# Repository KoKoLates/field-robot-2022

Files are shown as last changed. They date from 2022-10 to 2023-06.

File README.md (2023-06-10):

# Field Robot 2022
###### tags: `ntu bme` 、 `field robot`

The hardware and source codes using for field robot competition 2022.

## Features
* System consists of nvidia jetson nano and Arduino mega 2560, with transmission via serial.
* Design the robotic arm and apply the inverse kinematic to control by giving the target position.
* Implements a lane tracking algorithm for synthetic grass paths using opencv image processing, allowing robot to follow along the appropriate path.

## Overview
[**circuit**](./circuit/) | [**robotic cart**](./robotic_cart/) | [**robotic arm**](./robotic_arm/) 
| [**resources**](./assets/resources/) | [**images**](./assets/images/)

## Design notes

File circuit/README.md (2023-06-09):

# Circuit Designs
`Electric components` 、 `circuit designs` <br>

__1. Computational Unit__ <br>

* arduino mega -> `dc motor control` / arduino nano -> `servo motor`
* raspberry pi 4 (`wip`/`template`)
* nvidia jetson nano

__2.Electrical Unit__ <br>

* IBT2 -> `H-Bridge`
* voltage converter `HW319-V6.0` / voltage indicator
* battery (`12v`) / battery pack (`5v/2a`) for computation unit
* emergency button `LA38`

__3.Sensors and Acuator__ <br>

* step motor and servo motor
* relay `SRD-05VDC-SL-C` -> water pump

## Implements
###### tags:  `controller`、 `h-bridge`、 `regulator`、 `dc motor`

* Testing the driven part that connect the dc motor with h-bridge (`L298n`) and `12v` dc battery (here we test on power supplier first).
* Using the arduino mega as the controller for `PWN` signal output.
* check the general switch and emergency button work properly.

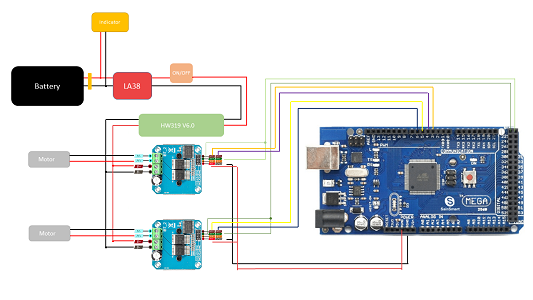
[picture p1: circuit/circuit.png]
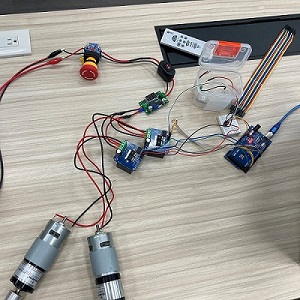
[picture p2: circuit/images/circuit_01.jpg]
 

###### tags: `eletric boxes` 、 `water-proof`
* The voltage for each components are indicating strictly.
* The all important unit for controll and operation are places inside the water-proof container both for robotic cart and for the dummy arm.
* There are maly three type of voltage being managed. `12v` for DC motor driven; two `5v` one is for the main controller and other sensors, the other is for the servo motor on the robotic arm which is driven by the servo driver (`PCA9685`).

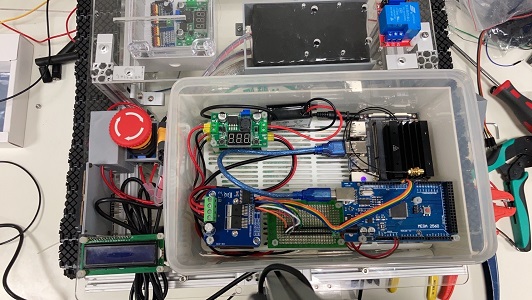
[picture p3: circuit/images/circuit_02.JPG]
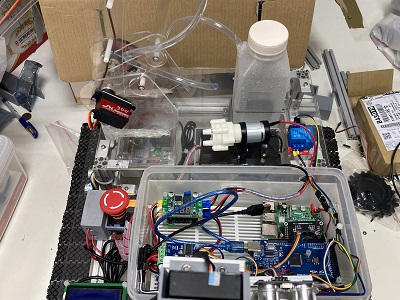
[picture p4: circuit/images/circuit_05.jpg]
 

---
[`Components Lists`](./components_list.pdf)

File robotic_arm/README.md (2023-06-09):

# Robotic Arm
`robotic arm` 、 `servo motor` 、 `gripper`

## Servo Motor
* `MG996R` for arm machenism / `SG90` for gripper.
* `PCA9685` servo driver for multi-servo PWM manager, control and driving.
* The import unit are stored inside the water-proof container.
*  [`motor driver | adafruit_PCA9685 pwm library`](http://adafruit.github.io/Adafruit-PWM-Servo-Driver-Library/html/class_adafruit___p_w_m_servo_driver.html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)

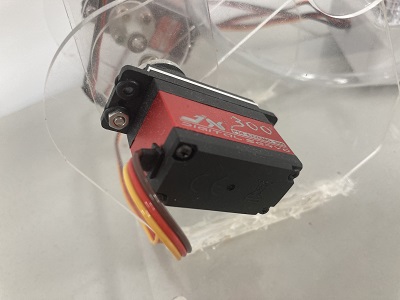
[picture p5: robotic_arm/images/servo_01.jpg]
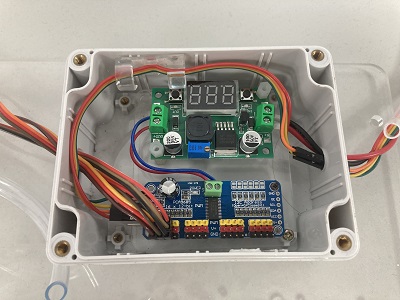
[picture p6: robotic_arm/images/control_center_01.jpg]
 

**Implements**

The are two type of design we use in the first
* Using another controller (`Aduino Nano`) for edge controll and communicate with main controller in `I2C` protocal
* Using the main controller in the center direcly.

## Robotic Arm
`robotic arm design` 、 `inverse kinematic`

__Designs in CAD__

The prototype of dummy robotic arm.


__Outcomes__

* The arm is manufactor in `acrylic` material.
* Using the `483` bearing for connect each components with free degree ratation.
* The Spacer could also help fix the wire and water pip.

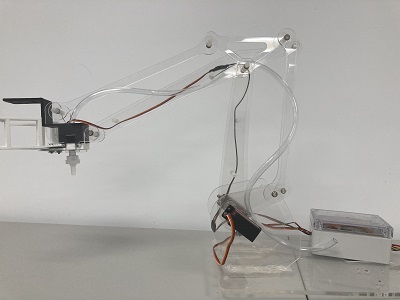
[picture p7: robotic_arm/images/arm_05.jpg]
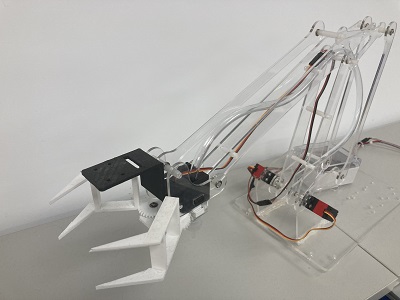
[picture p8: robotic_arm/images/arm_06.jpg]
 

__Inverse Kinematic__

For more convinent to controll the robot arm to grip the specific object. We use the inverse kinematic to calculate that by giving the object position, and the cooresponding servo angle would be. Thus, we could using some object detection algorithms to get the coordinate of object, then using the `API` we build to controll the arm properly.

* `resetInit()` reset the robotic arm to the initialize status.
* `moveTo(int x, int y)` set the end side (griper side) to the cooresponding position coordinate in the space.

## Gripper
We design a simple gripper for the object gripping.

* `SG90` servo motor.
* Small camera for `depth` information update.
* check valve and pip for watering task.

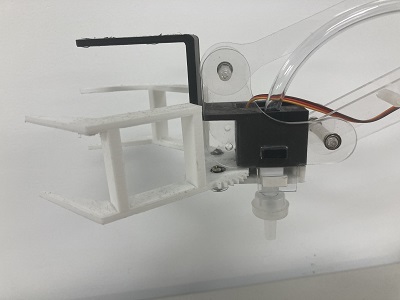
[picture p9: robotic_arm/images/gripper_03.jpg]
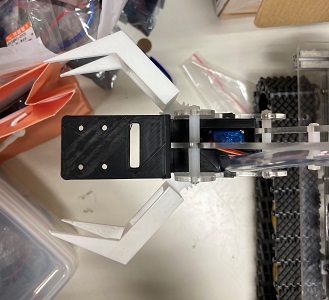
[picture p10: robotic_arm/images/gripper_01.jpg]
 

**API**
* `grab()` set the gripper close to gripping the object.
* `ungrab()` release the gripper.

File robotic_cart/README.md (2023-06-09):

# Robotic Cart
`robotic cart` 、 `side panel` 

## Scroll wheel and Support Structures
Due to the robot is go through in the outdoor field environments, we hope to design `shock absorber` 、 `continuous track` scroll wheel.

__1. Designs in CAD__

* crank rocker mechanism.
* springs and bearings.

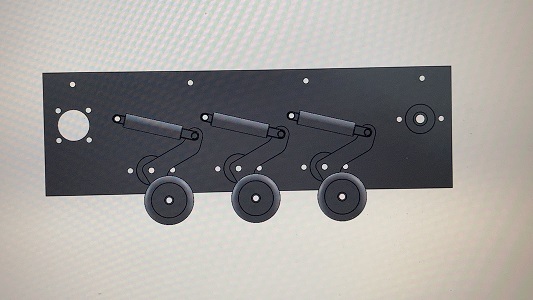
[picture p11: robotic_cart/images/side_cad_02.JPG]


__2. Wheel Axles__

* lathing two axles for the back wheel.

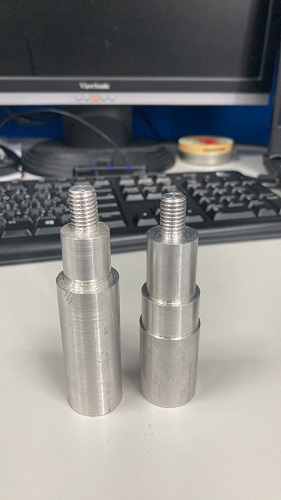
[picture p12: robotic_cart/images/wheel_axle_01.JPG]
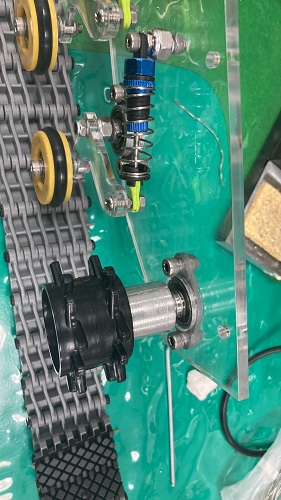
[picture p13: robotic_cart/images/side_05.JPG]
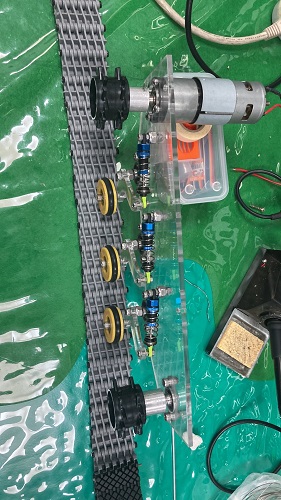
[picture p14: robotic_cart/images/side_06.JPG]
  

__3. Outcomes__

* The track is driven by the `DC motor` in the front.
* Once encounter any strike, the spring and machanism would absorb the shock.

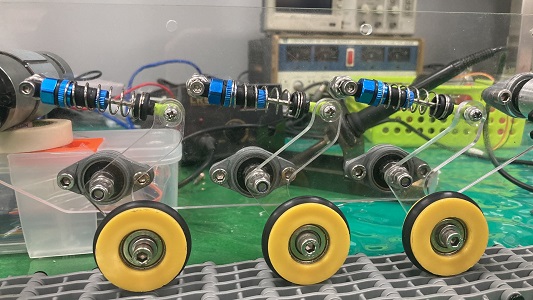
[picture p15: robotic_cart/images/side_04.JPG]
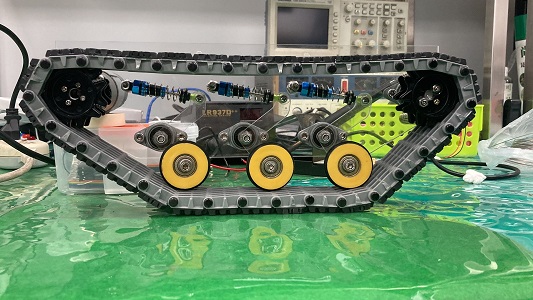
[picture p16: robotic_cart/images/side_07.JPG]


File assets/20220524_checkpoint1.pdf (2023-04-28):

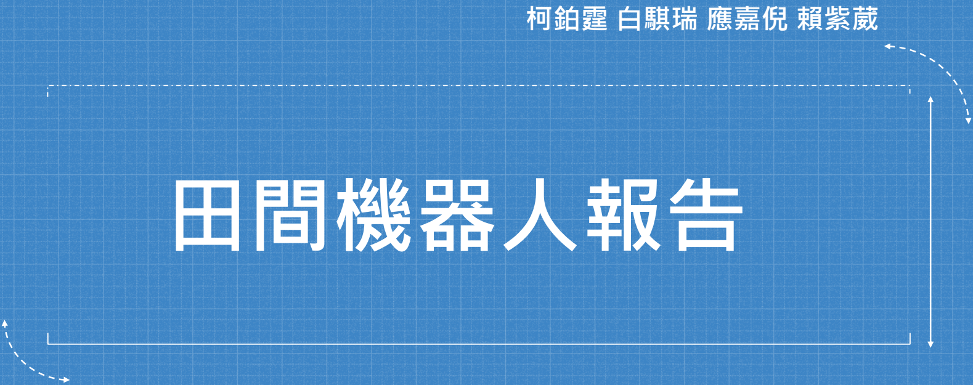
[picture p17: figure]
田間機器人報告; 柯鉑霆 白騏瑞 應嘉倪 賴紫葳

目錄

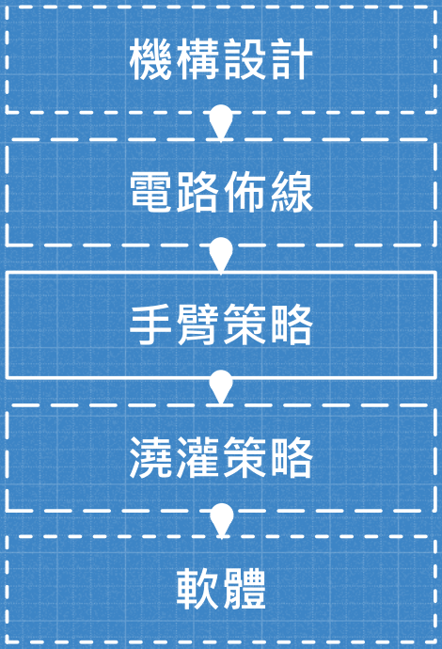
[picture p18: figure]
電路佈線; 手臂策略; 機構設計; 澆灌策略

# 機構設計

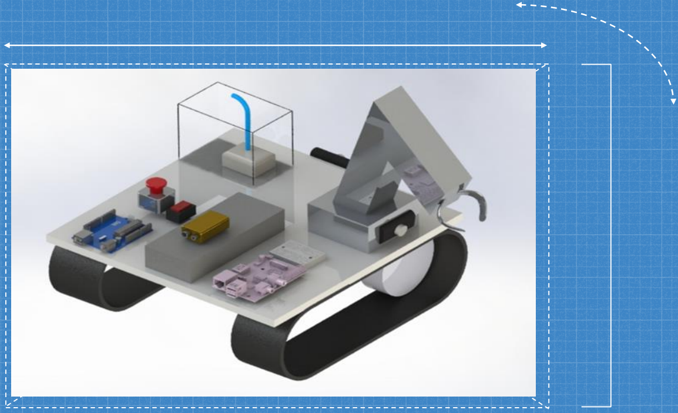
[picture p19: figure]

### - 正方形車底板

### - 一層設計

### - 鋁擠、壓克力板

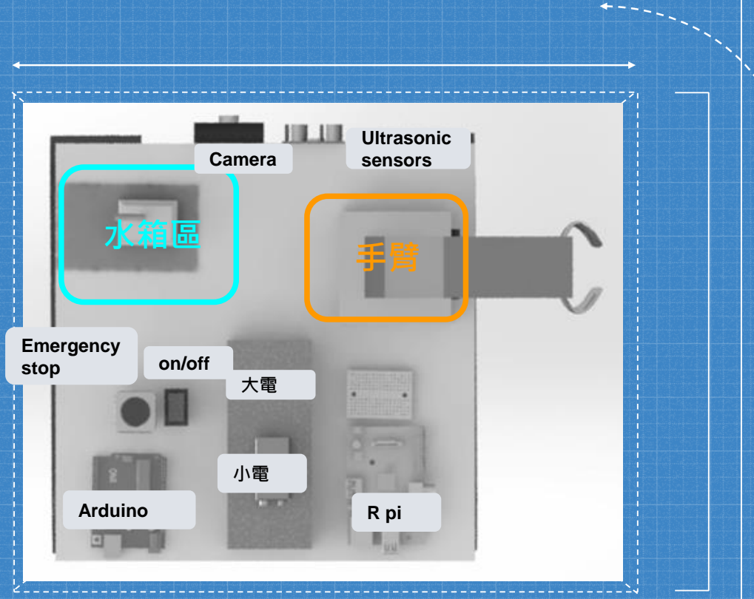
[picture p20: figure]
水箱區; Arduino; Emergency stop; on/off; Camera; Ultrasonic sensors

# 機構設計

### - 擺放位置安排

車體最前端— 視野清晰
前半部分— 重心位置
後半部分—方便接線&調整

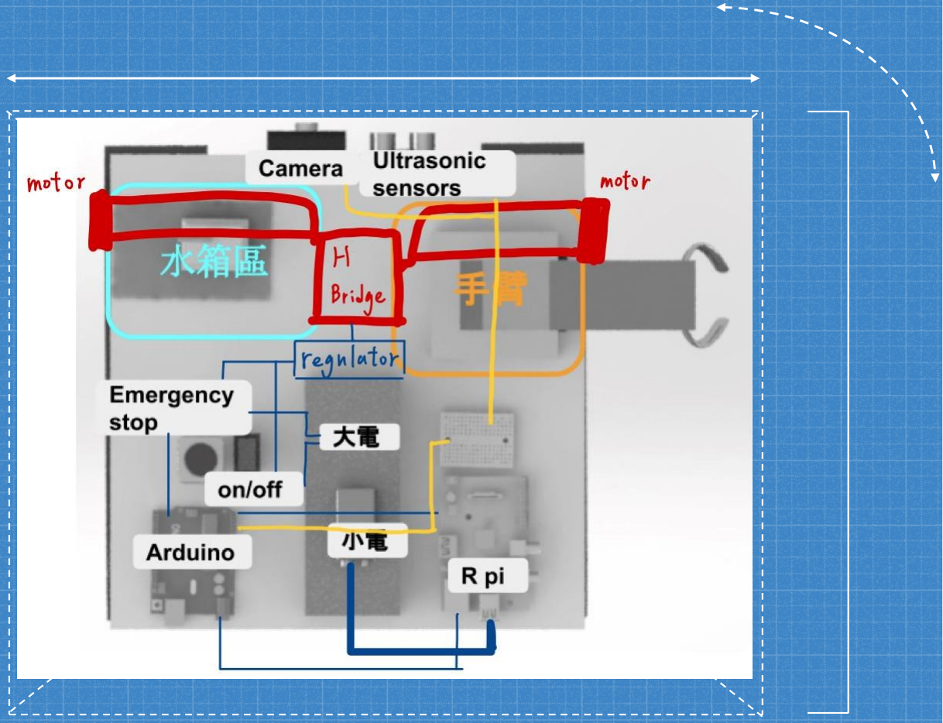
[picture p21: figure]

# 電路佈線

# 手臂策略

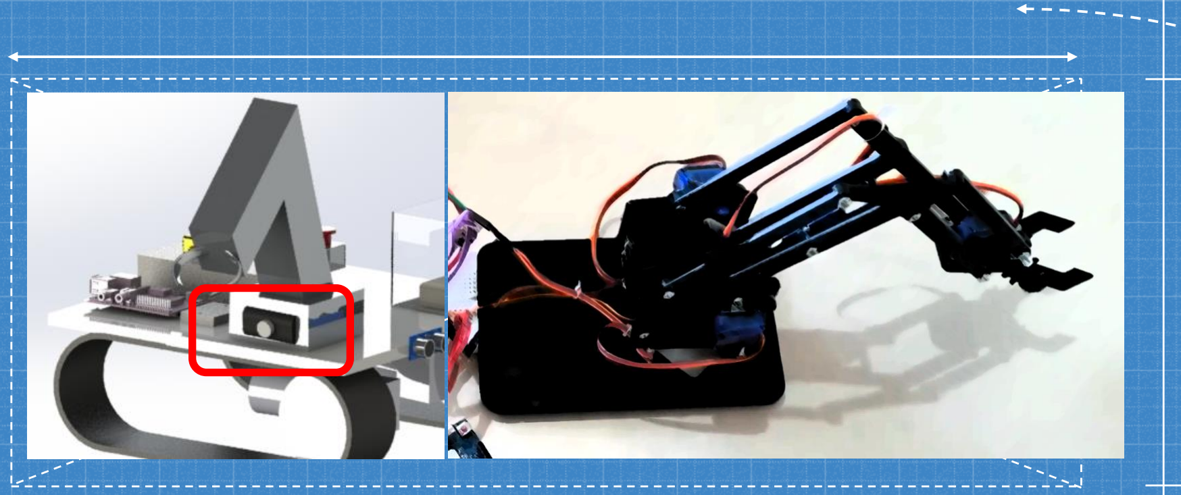
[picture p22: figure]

- 二軸

### - 三個步進馬達

### - 相機位置固定

# 澆灌策略

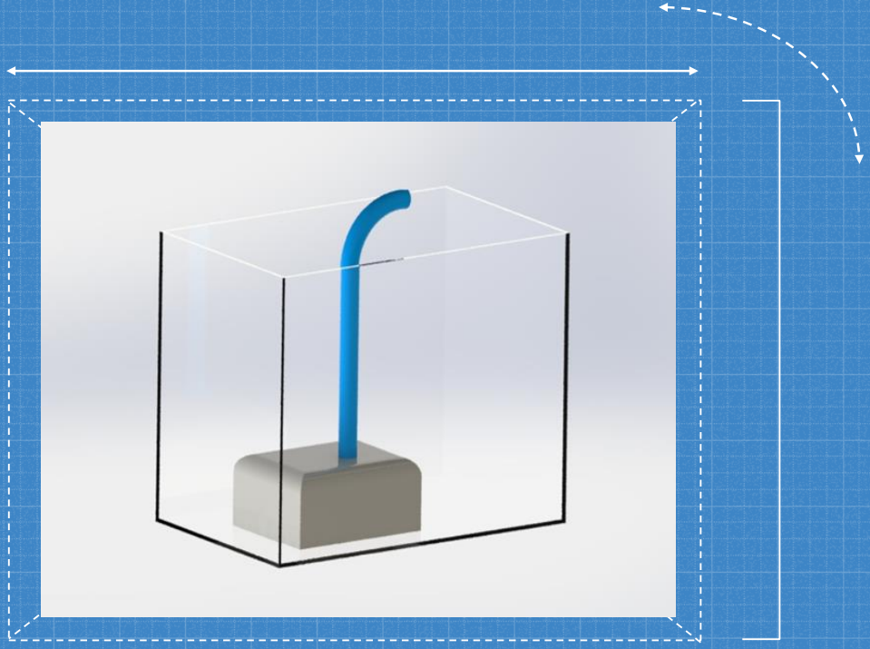
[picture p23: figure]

### - 抽水方式 小型沉水式馬達

### - 水管連接夾爪

### - 定位方式同手臂策略

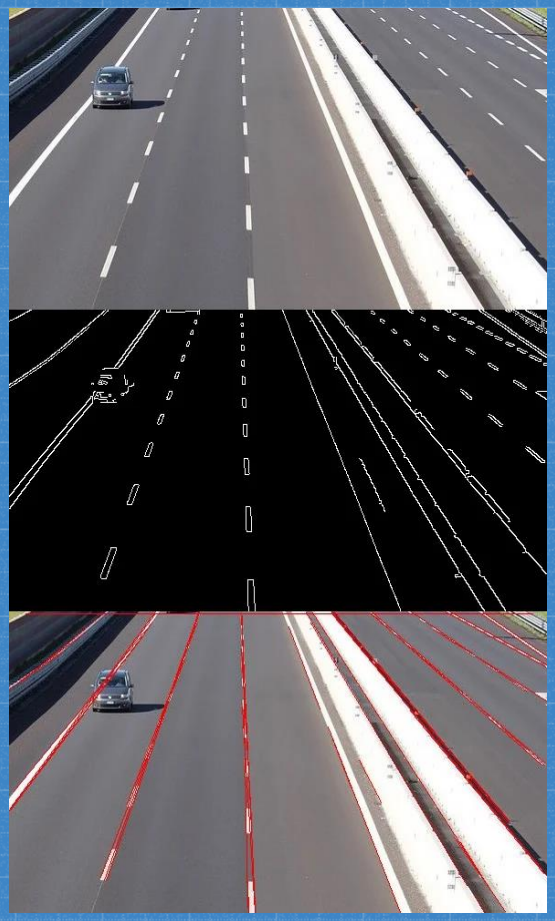
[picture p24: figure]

軟體

### - Path Finding

方案一: 影像處理

灰階 、 平滑化、邊緣檢測、

閾值調整、霍夫直線檢測、路徑線段與邊緣校準

軟體


### - Path Finding

方案二: segNet

以VGG16為基礎，做segnet圖像語意分析訓練

* 對邊緣與邊界位置的不確定性較大，可能影響

後續循跡的運算與誤差，在此僅提出可用方案

SOURCE:
https://towardsdatascience.com/lane-detection-with-deep-learning-part-2-3ba559b5c5af

軟體


### - Lane Tracking

Lane Detection 後取的路徑邊緣，

做處理與運算後預期能取得路徑

中線，以此做為控制目標。並將

控制訊號傳送給控制器做馬達輸

出調整。

軟體

### - Mark Recognizion

利用影像處理取的標示特徵與形狀

convexityDefects

convexHull


findContours

* Shape Detection / Color Detection

應該是可以直接利用顏色來判斷物件

屬性，若物件位置固定，則整體取物

程式相對不複雜。

### - Object Detection

# 分工方式

成員 | 工作內容
柯鉑霆 | 軟體架構、機構設計
白騏瑞 | 機構設計
應嘉倪 | 電路佈線、機構設計
賴紫葳 | 機構設計

# Thanks!

# ANY QUESTIONS?

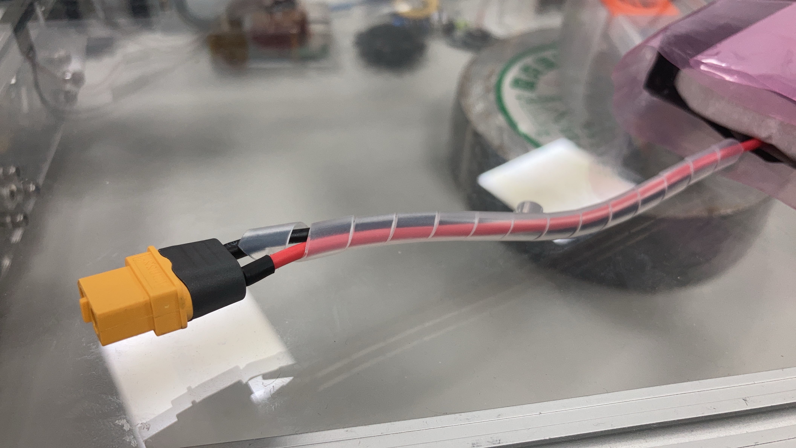
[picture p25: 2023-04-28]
assets/resources/XT60_connector_02.JPG

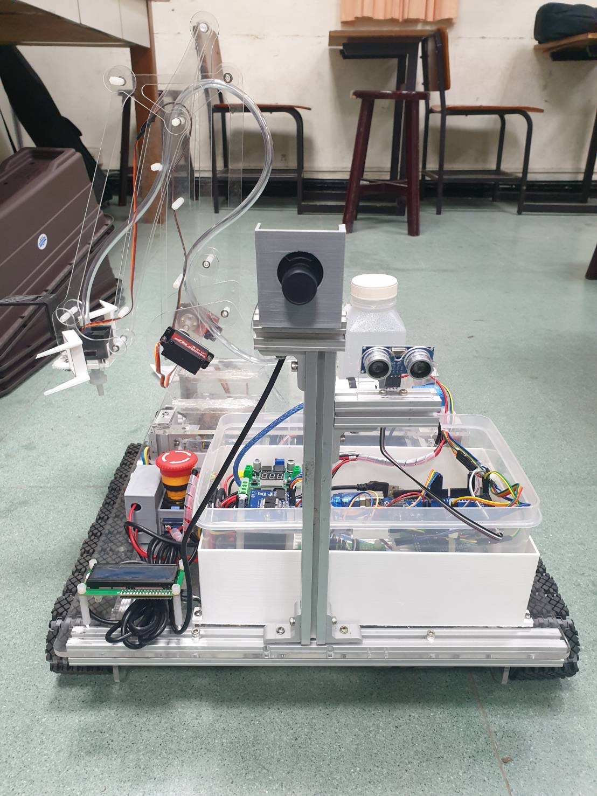
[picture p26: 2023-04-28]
assets/images/front_side_v2_01.JPG

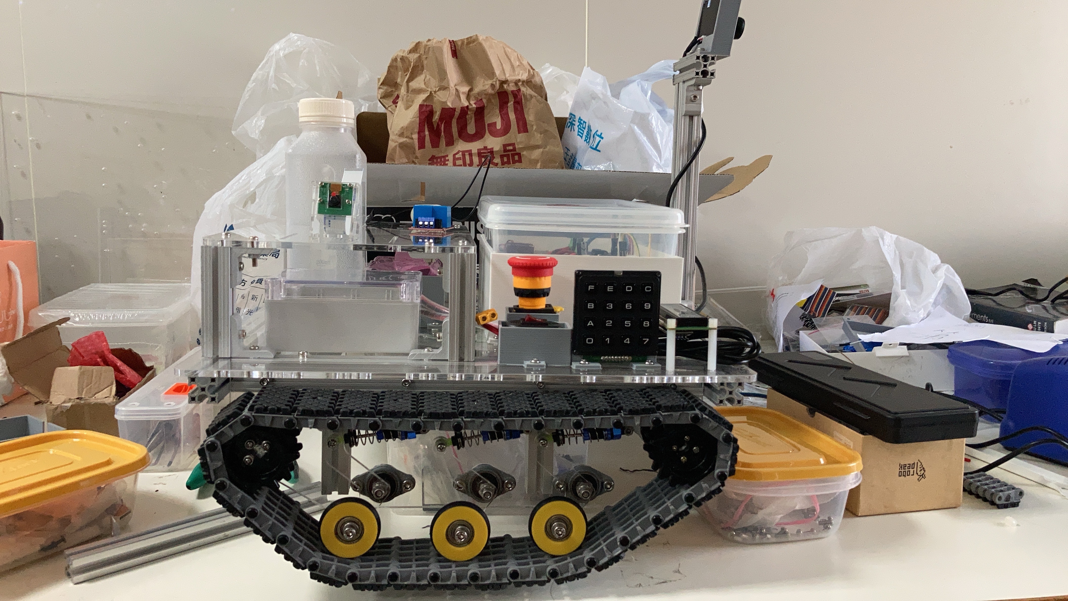
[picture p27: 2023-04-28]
assets/images/right_side_v1_01.JPG

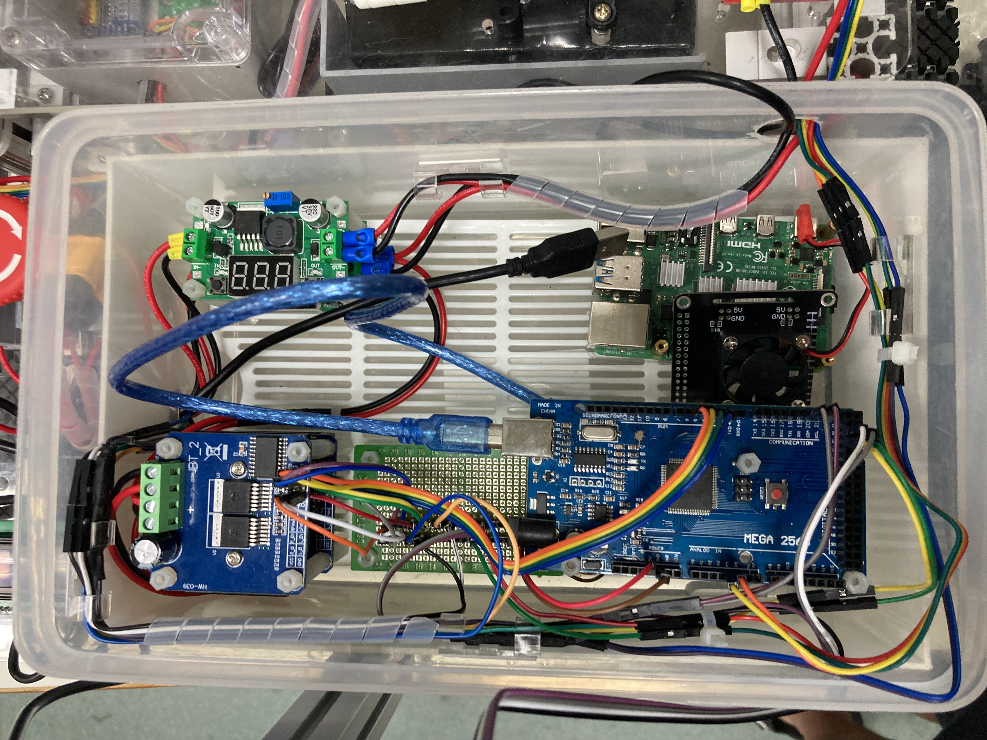
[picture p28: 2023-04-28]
circuit/images/circuit_07.jpg

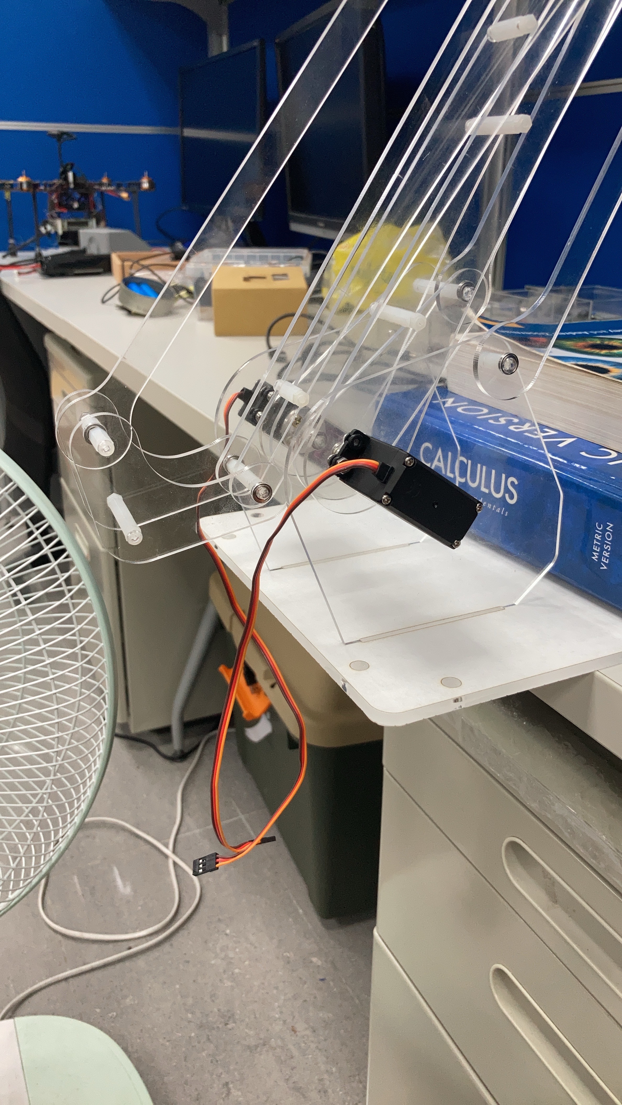
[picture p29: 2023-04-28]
robotic_arm/images/arm_01.JPG

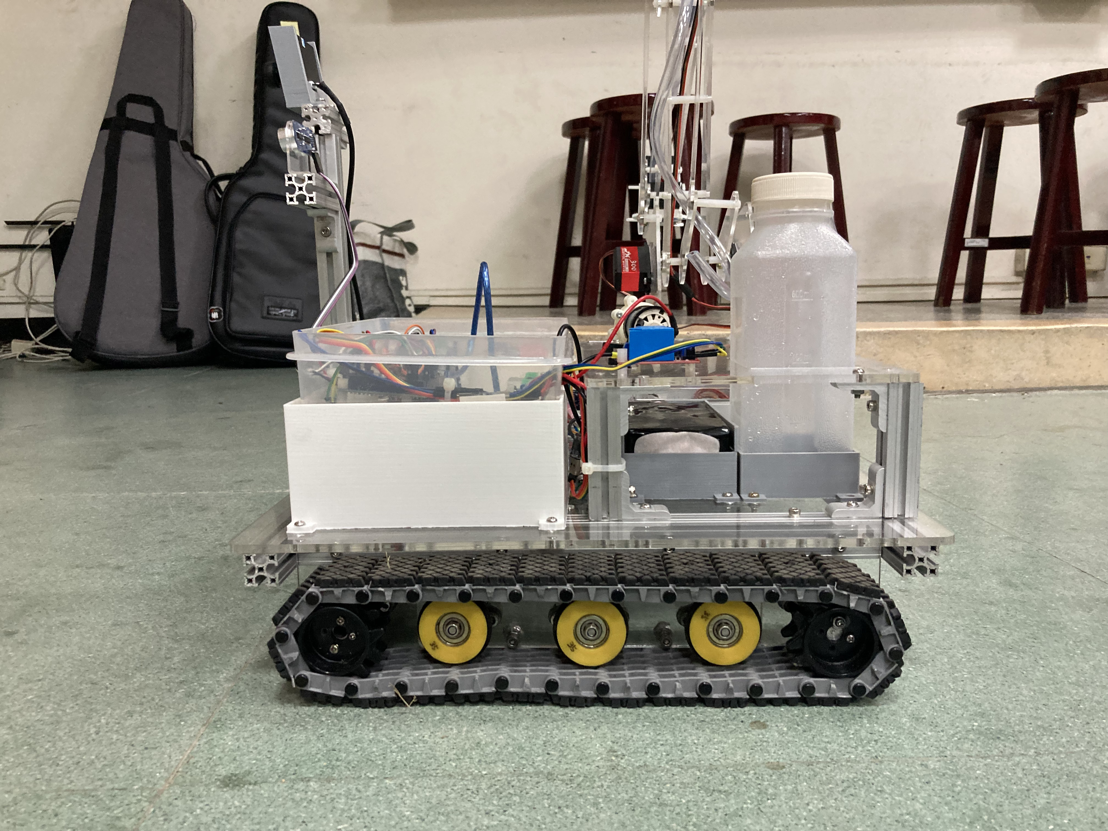
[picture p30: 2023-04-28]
assets/images/left_side_v2_01.jpg

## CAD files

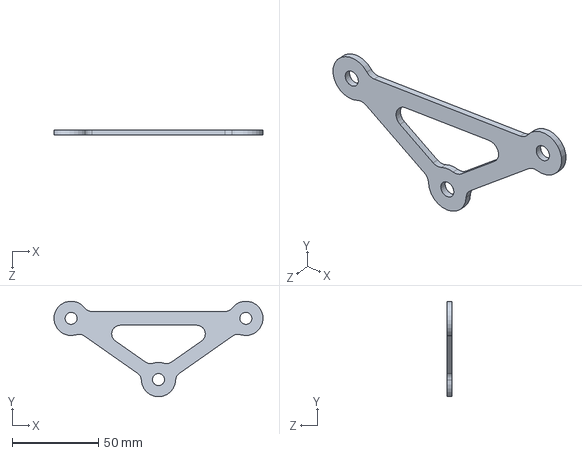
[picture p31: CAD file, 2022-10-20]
robotic_arm/hardware/arm2.SLDPRT
121.5 x 55.5 x 3.00 mm

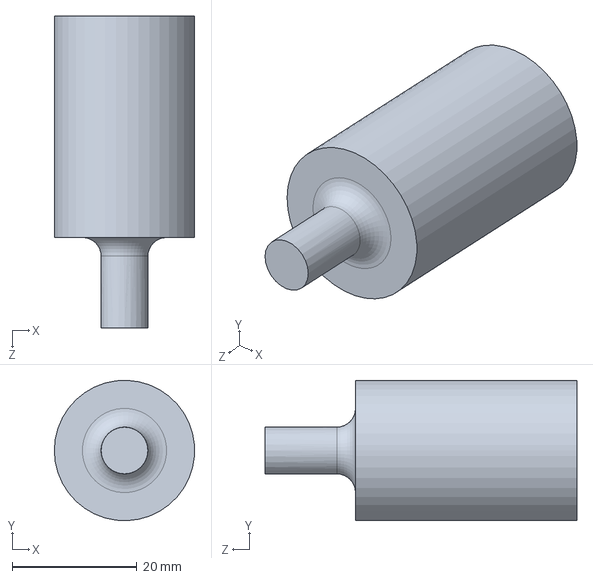
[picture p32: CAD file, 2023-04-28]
robotic_cart/big_wheel.SLDPRT
22.5 x 22.5 x 50.0 mm

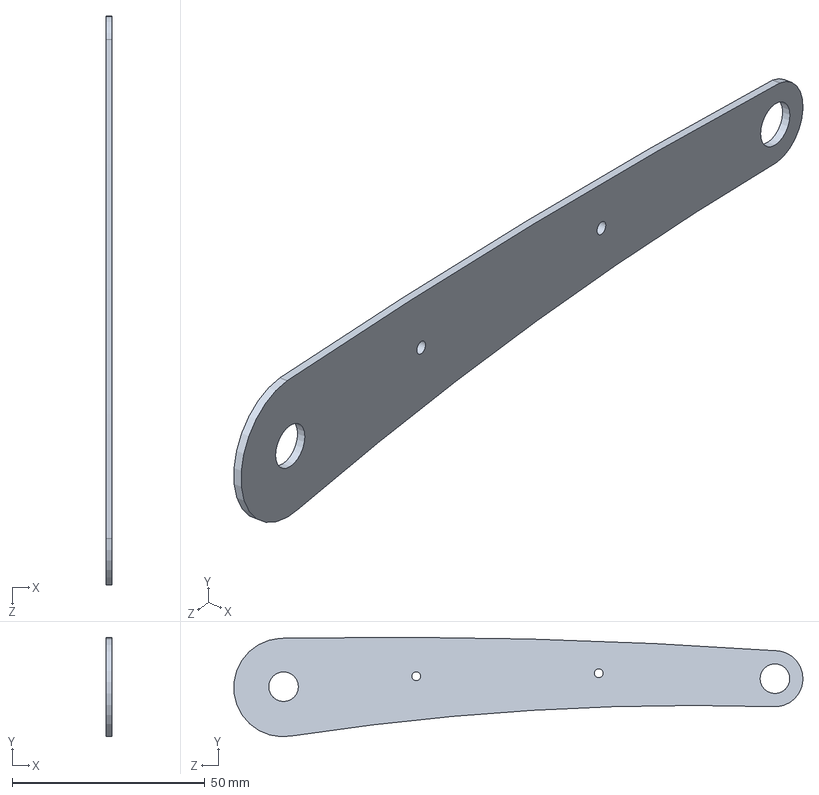
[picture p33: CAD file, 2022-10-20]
robotic_arm/hardware/arm4-2.SLDPRT
1.50 x 25.8 x 147.8 mm

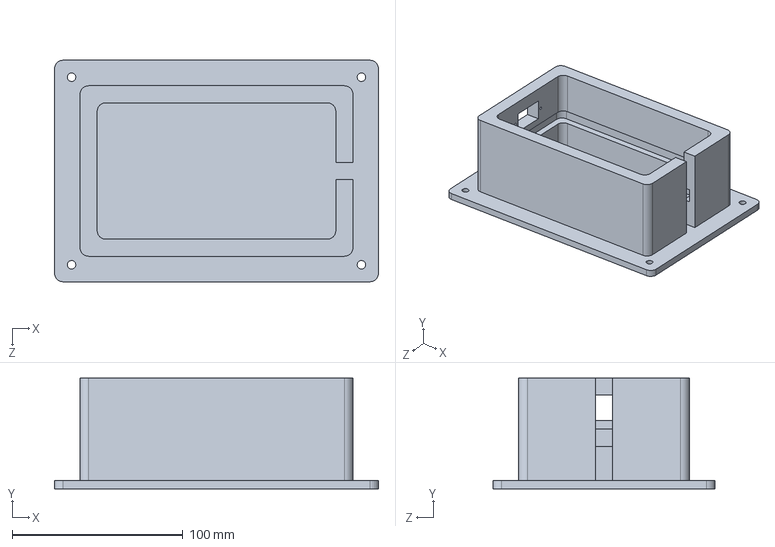
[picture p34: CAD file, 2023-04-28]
robotic_cart/battery.SLDPRT
190.0 x 65.0 x 130.0 mm

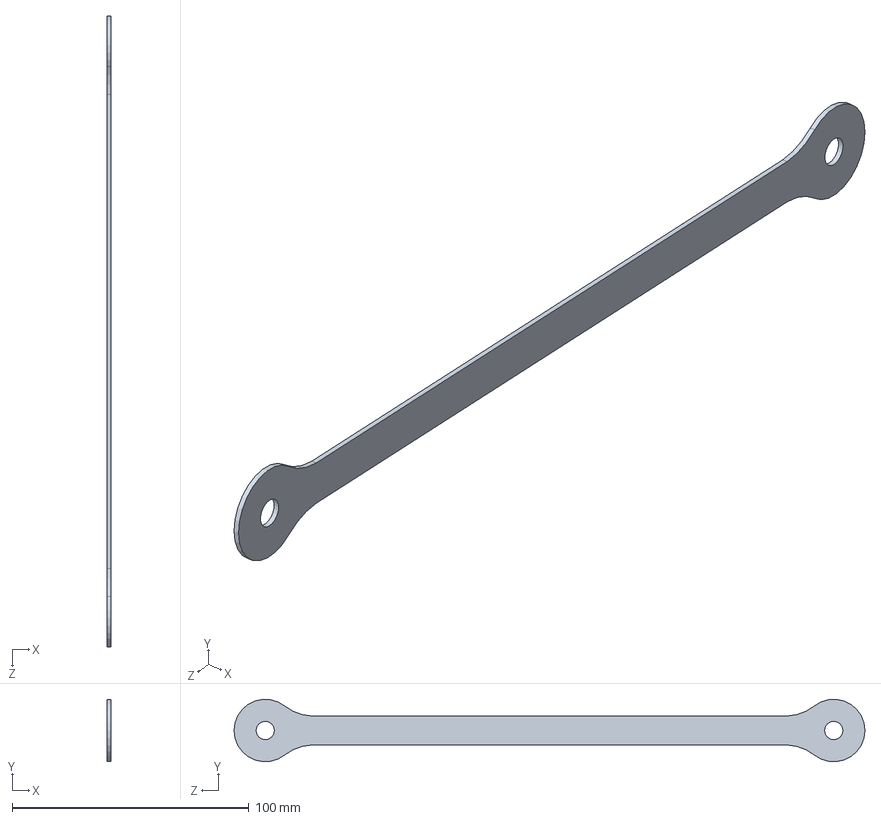
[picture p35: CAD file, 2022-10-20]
robotic_arm/hardware/arm5_front.SLDPRT
1.50 x 26.3 x 266.4 mm

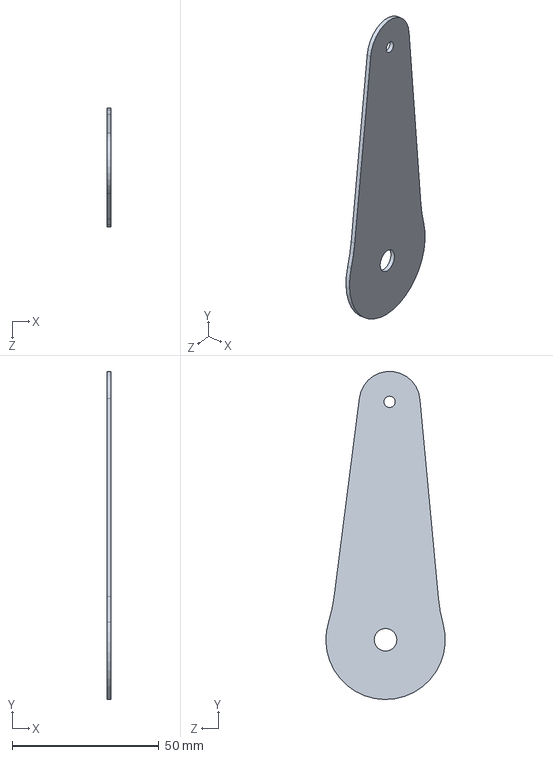
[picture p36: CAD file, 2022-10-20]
robotic_arm/hardware/arm7-2.SLDPRT
1.50 x 111.6 x 40.6 mm

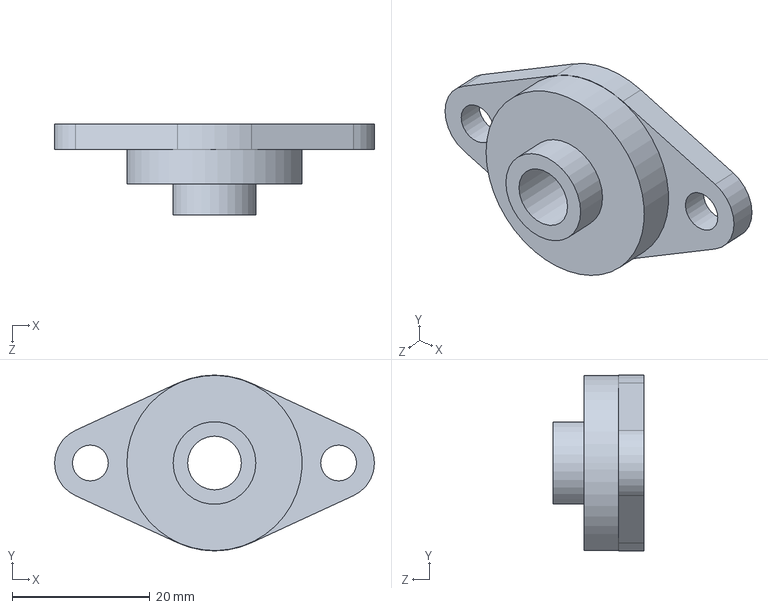
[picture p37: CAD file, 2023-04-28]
robotic_cart/bearing.SLDPRT
46.4 x 25.5 x 13.2 mm

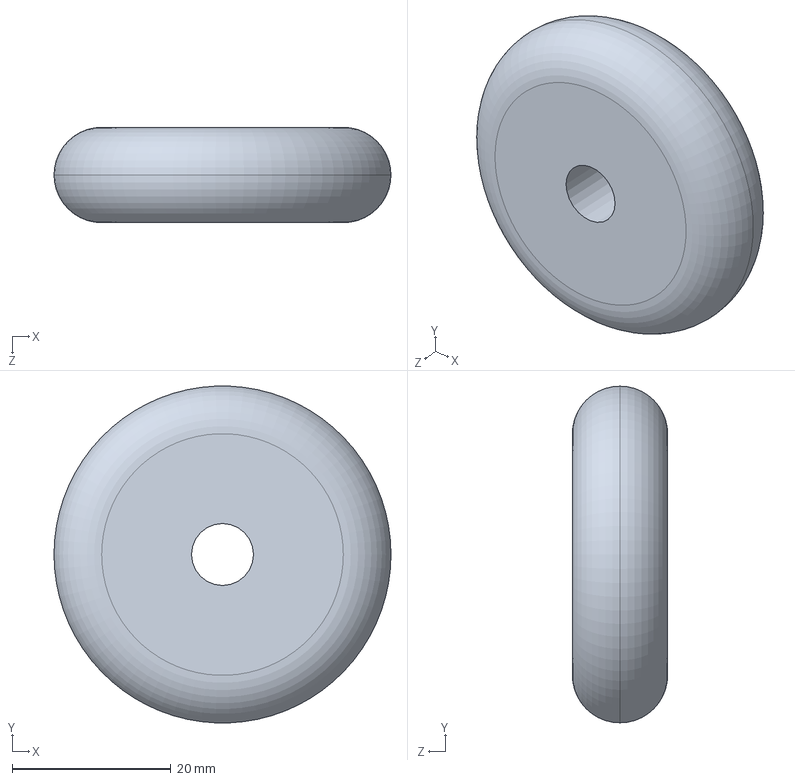
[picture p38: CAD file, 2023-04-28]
robotic_cart/small_wheel.SLDPRT
42.4 x 42.4 x 12.0 mm

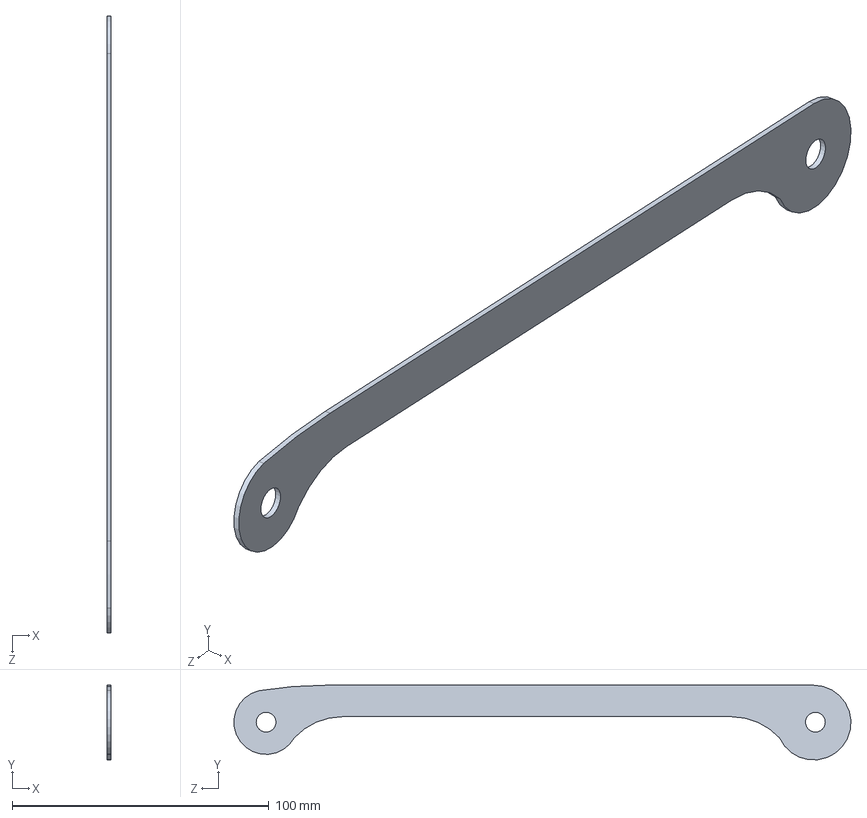
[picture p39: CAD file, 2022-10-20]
robotic_arm/hardware/arm6_sup.SLDPRT
1.50 x 29.0 x 240.1 mm

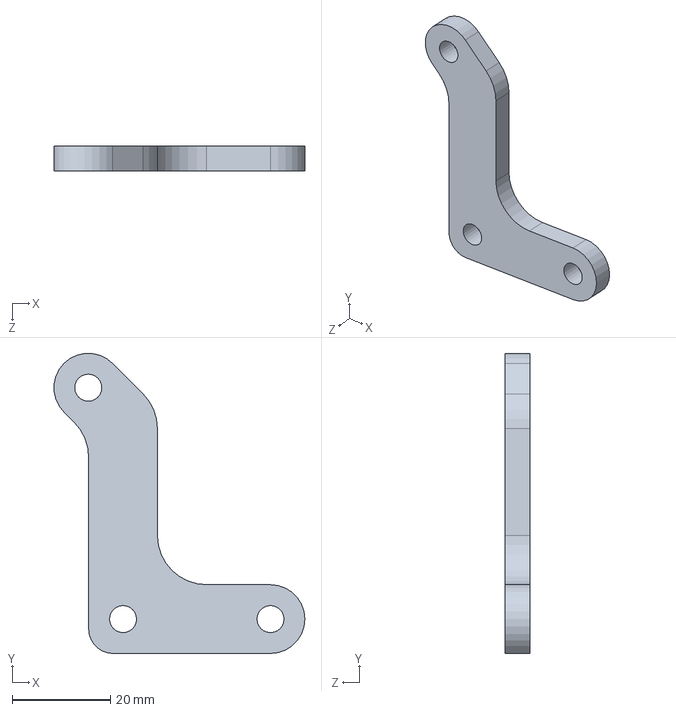
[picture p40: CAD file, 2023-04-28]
robotic_cart/support.SLDPRT
51.0 x 61.0 x 5.00 mm

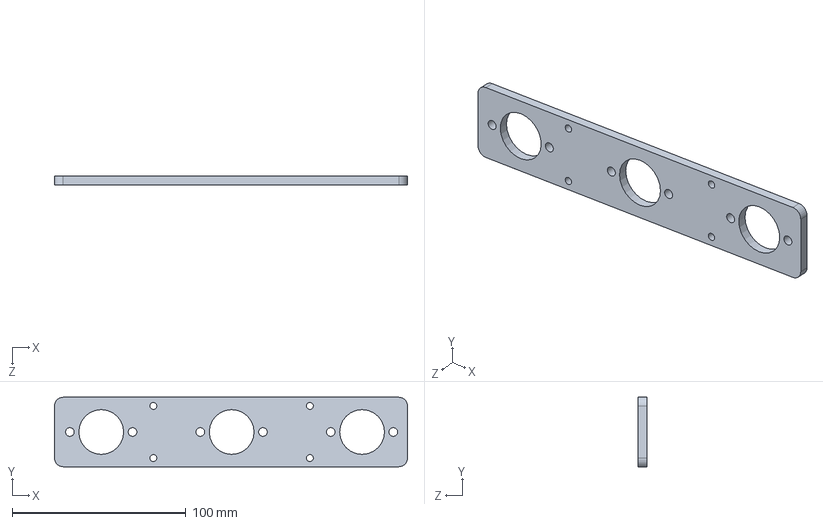
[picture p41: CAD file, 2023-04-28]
robotic_cart/com.SLDPRT
203.0 x 40.0 x 5.00 mm

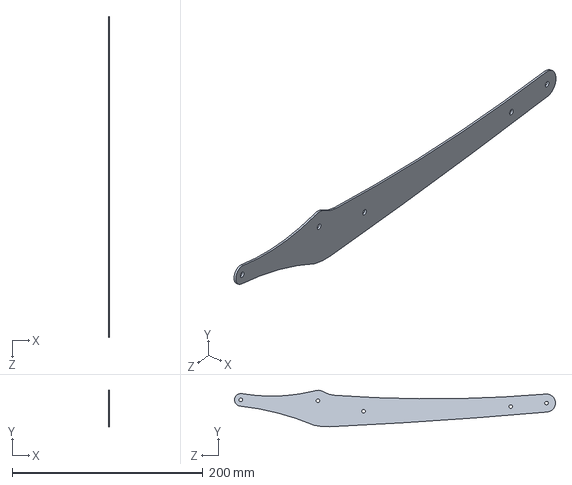
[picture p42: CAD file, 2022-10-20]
robotic_arm/hardware/arm3.SLDPRT
1.50 x 38.3 x 337.0 mm

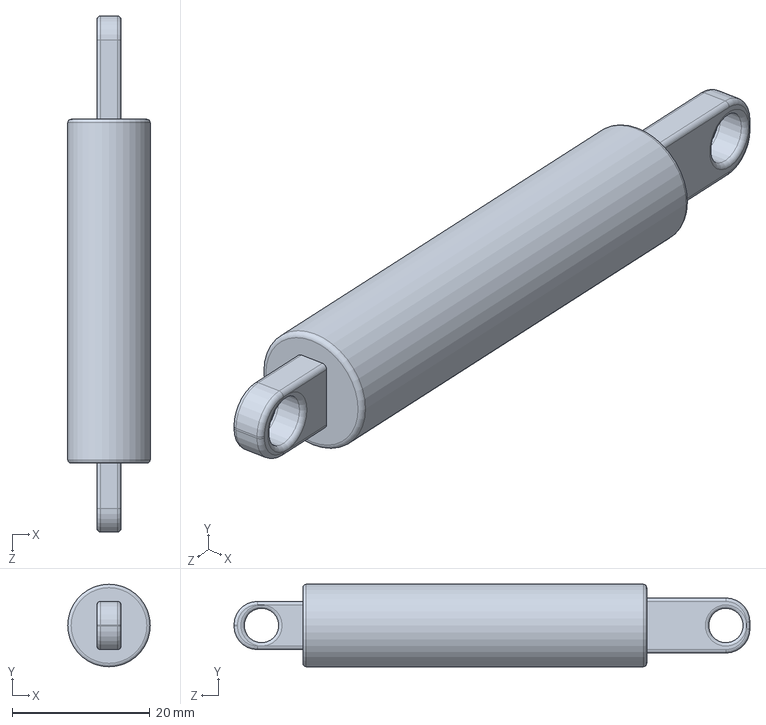
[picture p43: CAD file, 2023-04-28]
robotic_cart/spring.SLDPRT
12.0 x 12.0 x 75.0 mm

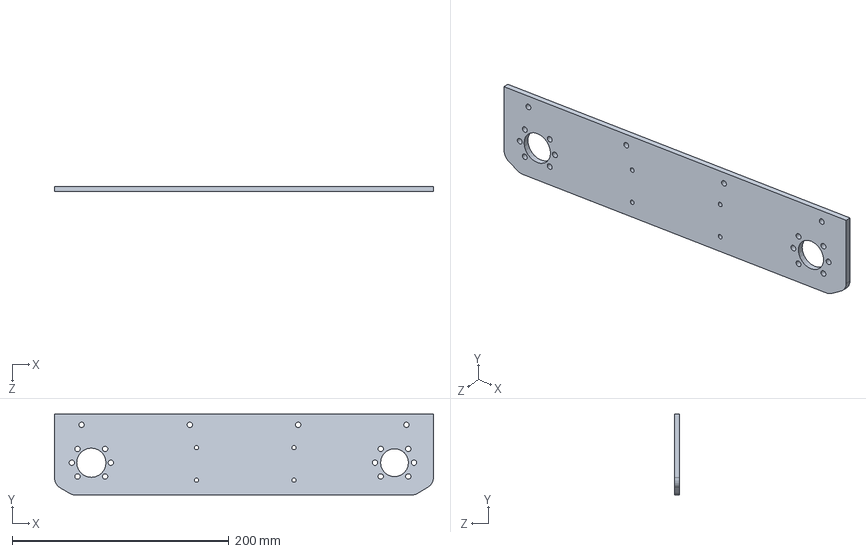
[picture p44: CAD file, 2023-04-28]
robotic_cart/side_v2.SLDPRT
350.0 x 74.8 x 5.00 mm

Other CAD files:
robotic_arm/hardware/arm_total.SLDPRT
robotic_arm/hardware/arm4-1.SLDPRT
robotic_arm/hardware/arm7.SLDPRT
robotic_arm/hardware/arm7-1.SLDPRT
robotic_arm/hardware/483_bear.SLDPRT
robotic_arm/hardware/arm1.SLDPRT
robotic_arm/hardware/arm4-3.SLDPRT
robotic_arm/hardware/arm4-4.SLDPRT
robotic_arm/hardware/arm4.SLDPRT
robotic_arm/hardware/arm5_back.SLDPRT
robotic_arm/hardware/arm8.SLDPRT
robotic_arm/hardware/arm_total.DWG
robotic_arm/hardware/arm_total.DXF
robotic_cart/side_v1.SLDPRT

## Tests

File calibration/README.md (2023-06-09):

# Camera Calibration
[`OpenCV | Camera Calibration`](https://docs.opencv.org/4.x/dc/dbb/tutorial_py_calibration.html)

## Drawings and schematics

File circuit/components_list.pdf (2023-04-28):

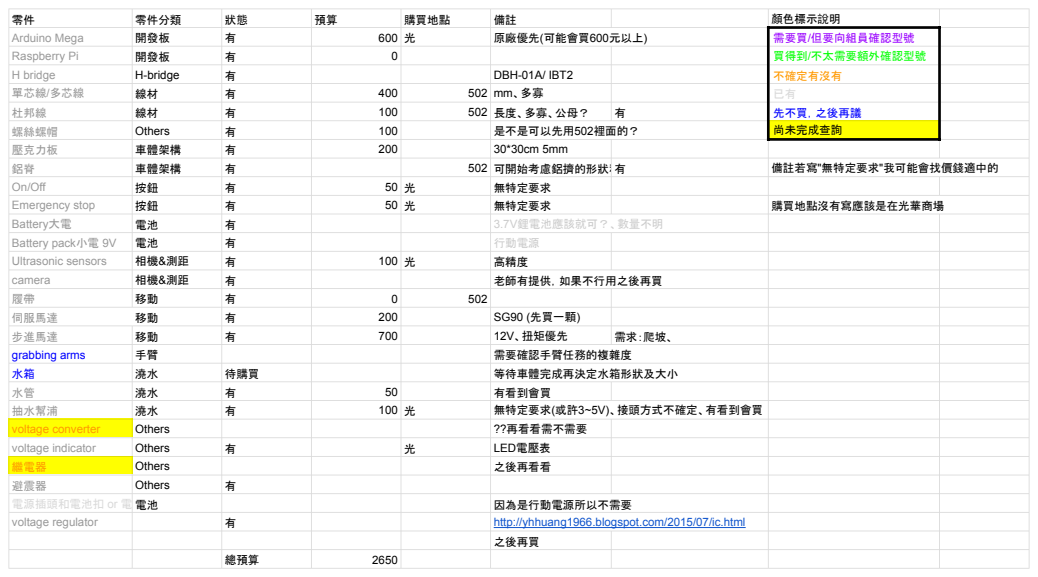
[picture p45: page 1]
零件分類; 購買地點; 顏色標示說明; 螺絲螺帽; Others; 是不是可以先用502裡面的？; 尚未完成查詢; 壓克力板; 車體架構; 502 可開始考慮鋁擠的形狀和長度 有; 備註若寫"無特定要求"我可能會找價錢適中的; On/Off; 無特定要求; Emergency stop; 購買地點沒有寫應該是在光華商場; Battery大電; 3.7V鋰電池應該就可？、數量不明; Battery pack小電 9V; 行動電源; Ultrasonic sensors; 高精度; camera; 老師有提供，如果不行用之後再買; 伺服馬達; SG90 (先買一顆); 步進馬達; 12V、扭矩優先; grabbing arms; 需要確認手臂任務的複雜度; 待購買; 等待車體完成再決定水箱形狀及大小; 有看到會買; 抽水幫浦; 無特定要求(或許3~5V)、接頭方式不確定、有看到會買; 電源插頭和電池扣 or 電池轉接器 電池; 因為是行動電源所以不需要; voltage regulator; http://yhhuang1966.blogspot.com/2015/07/ic.html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

Arduino Mega | 開發板 有 600 光 原廠優先(可能會買600元以上) | 需要買/但要向組員確認型號
Raspberry Pi 開發板 有 0 | | 買得到/不太需要額外確認型號
H bridge | H-bridge 有 DBH-01A/ IBT2 | 不確定有沒有
單芯線/多芯線 線材 有 400 502 mm、多寡 杜邦線 線材 有 100 502 長度、多寡、公母？ 有 | | 已有 先不買，之後再議

voltage converter | Others ??再看看需不需要
voltage indicator | Others 有 光 LED電壓表
繼電器 | Others 之後再看看
避震器 | Others 有

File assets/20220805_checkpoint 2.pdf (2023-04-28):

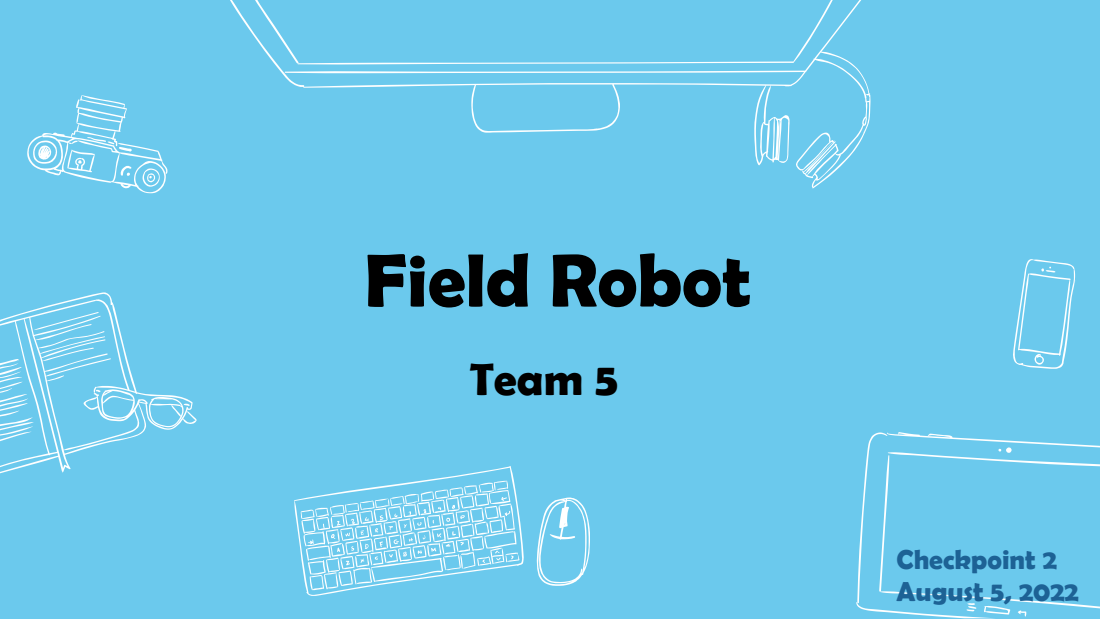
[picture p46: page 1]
Field Robot; Team 5; Checkpoint 2 August 5, 2022

目錄

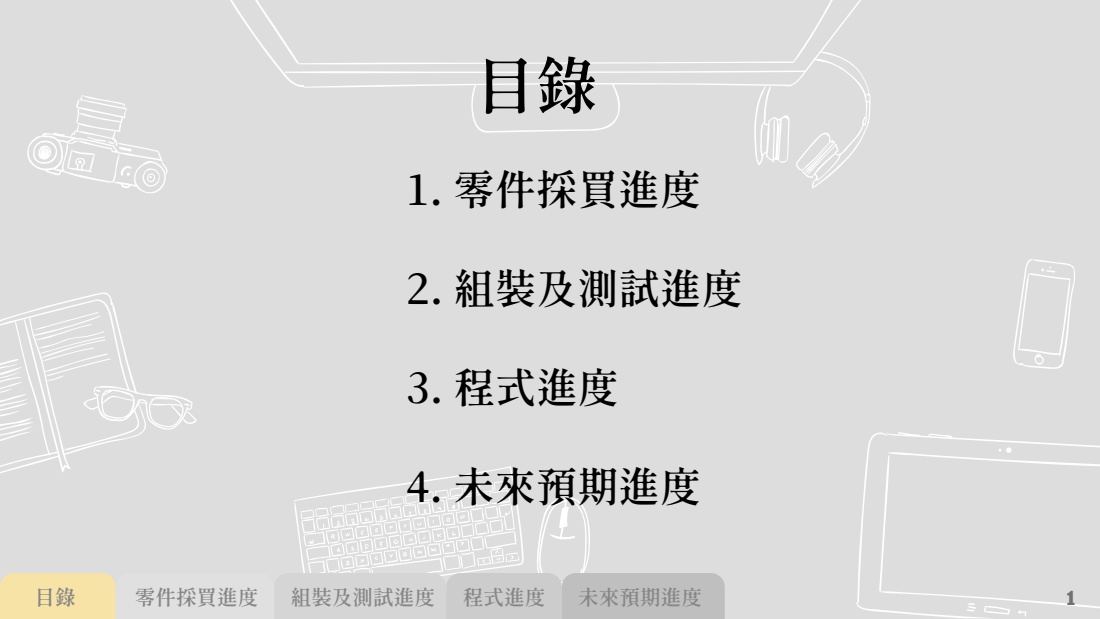
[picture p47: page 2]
零件採買進度; 組裝及測試進度; 程式進度; 未來預期進度; 1. 零件採買進度; 2. 組裝及測試進度; 3. 程式進度; 4. 未來預期進度

# 零件採買進度

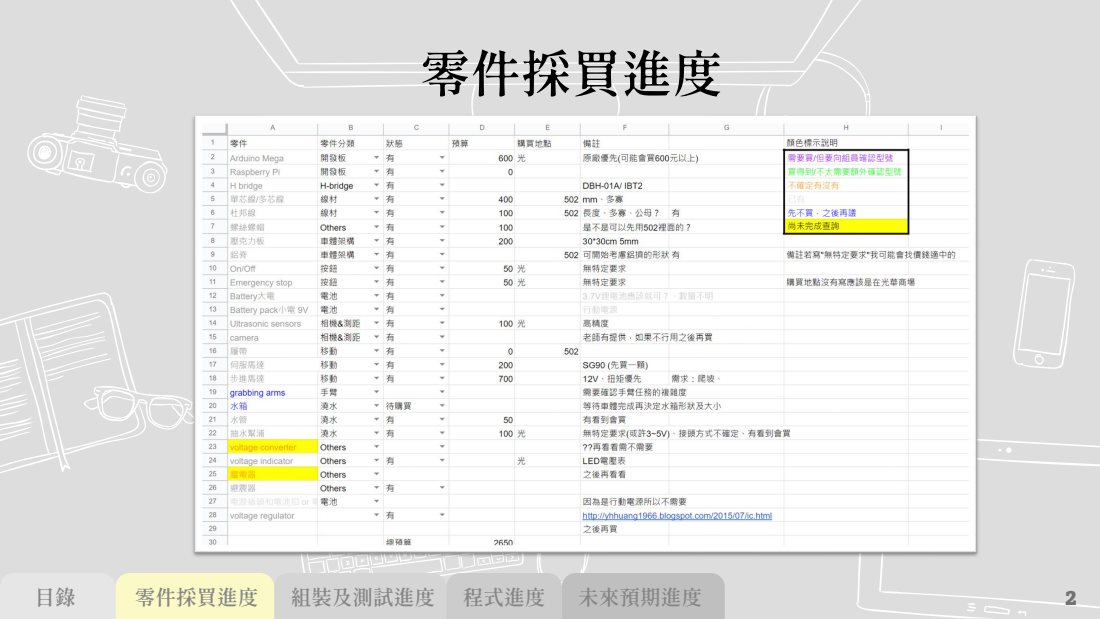
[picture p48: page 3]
零件採買進度; 組裝及測試進度; 程式進度; 未來預期進度

# 組裝及測試進度―車底板

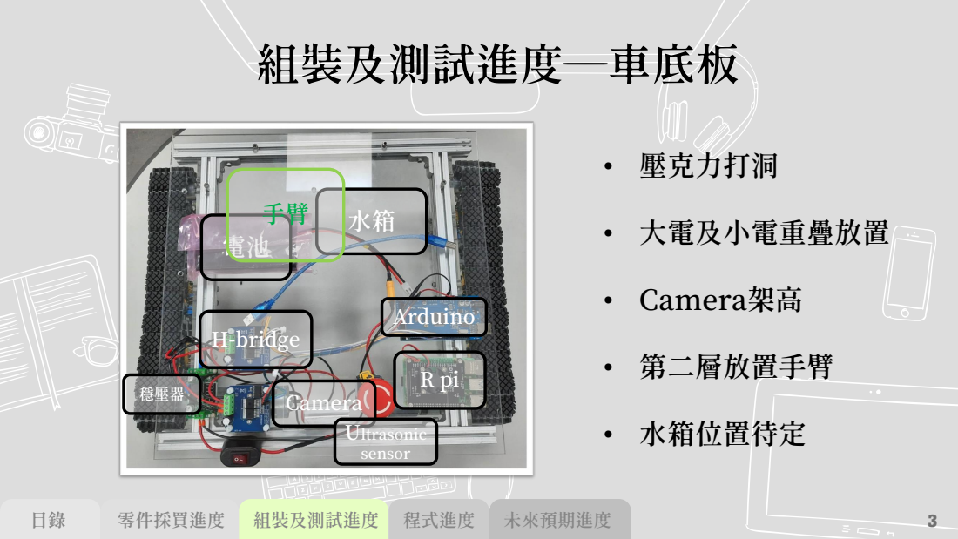
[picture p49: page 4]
• 壓克力打洞; • 大電及小電重疊放置; • Camera架高; • 第二層放置手臂; • 水箱位置待定; H-bridge; Arduino; Camera 穩壓器; Ultrasonic; sensor

# 組裝及測試進度―車底板

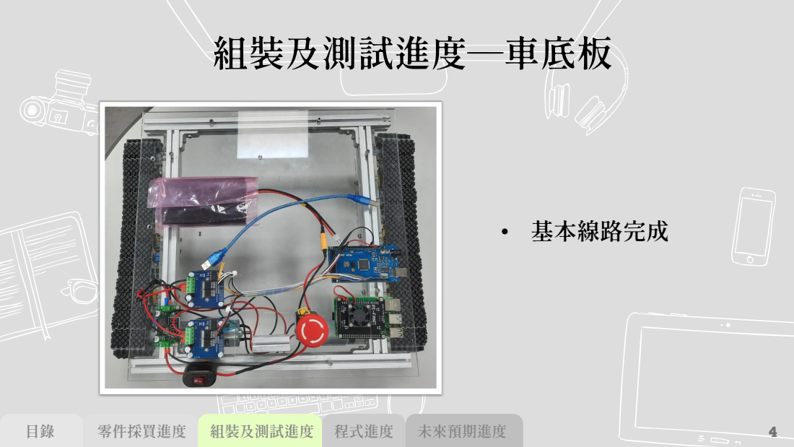
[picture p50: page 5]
• 基本線路完成

# 組裝及測試進度―側板

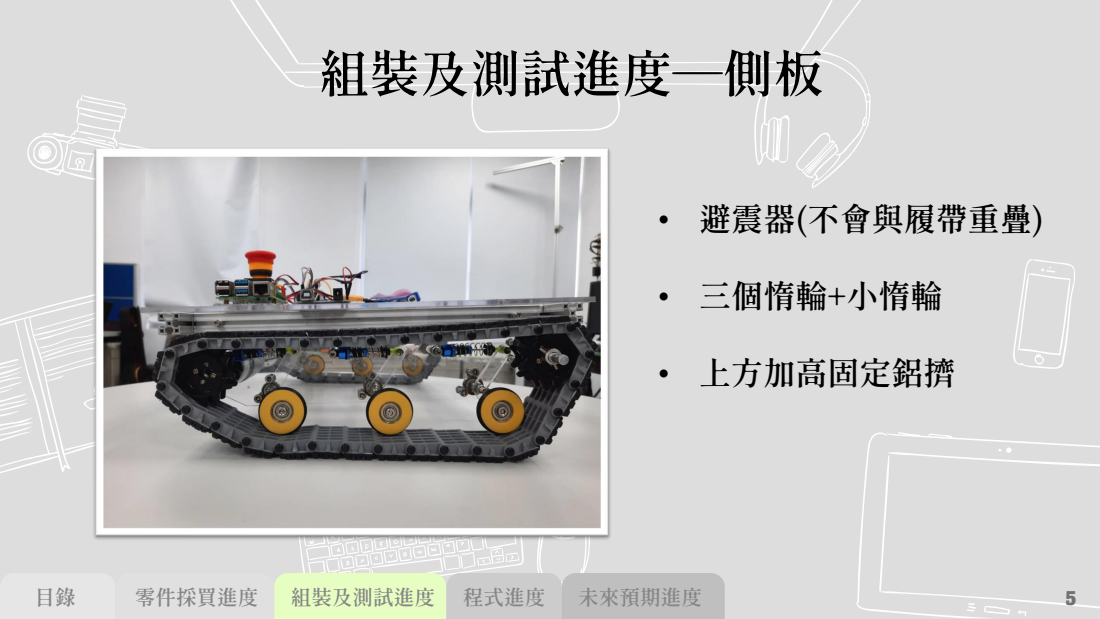
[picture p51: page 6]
• 避震器(不會與履帶重疊); • 三個惰輪+小惰輪; • 上方加高固定鋁擠

# 組裝及測試進度―側板

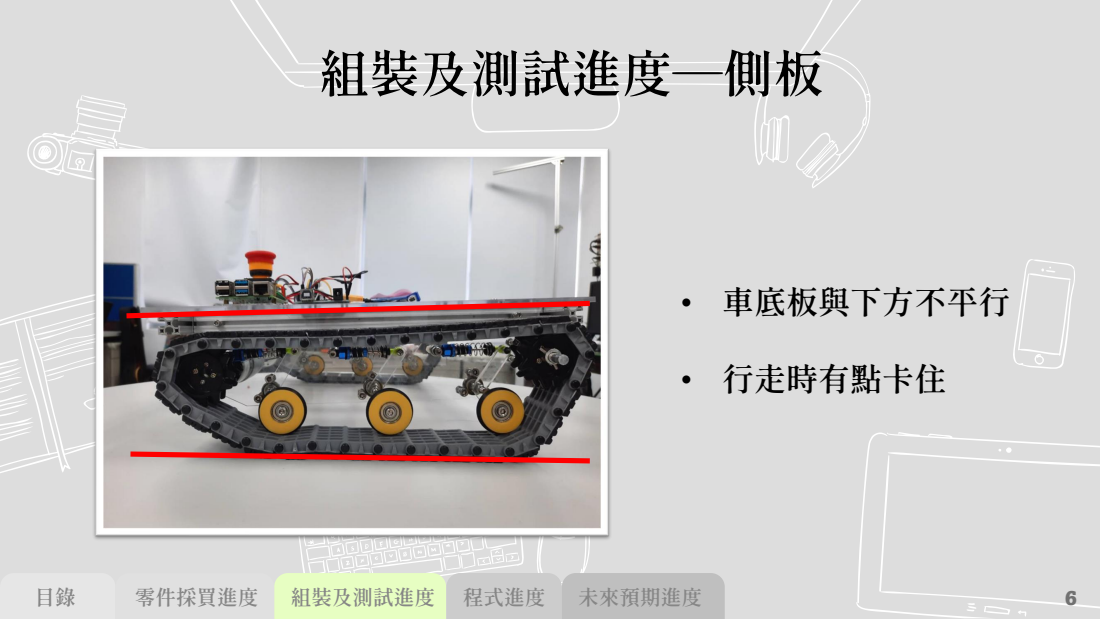
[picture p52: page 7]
• 車底板與下方不平行; • 行走時有點卡住

# 組裝及測試進度―側板

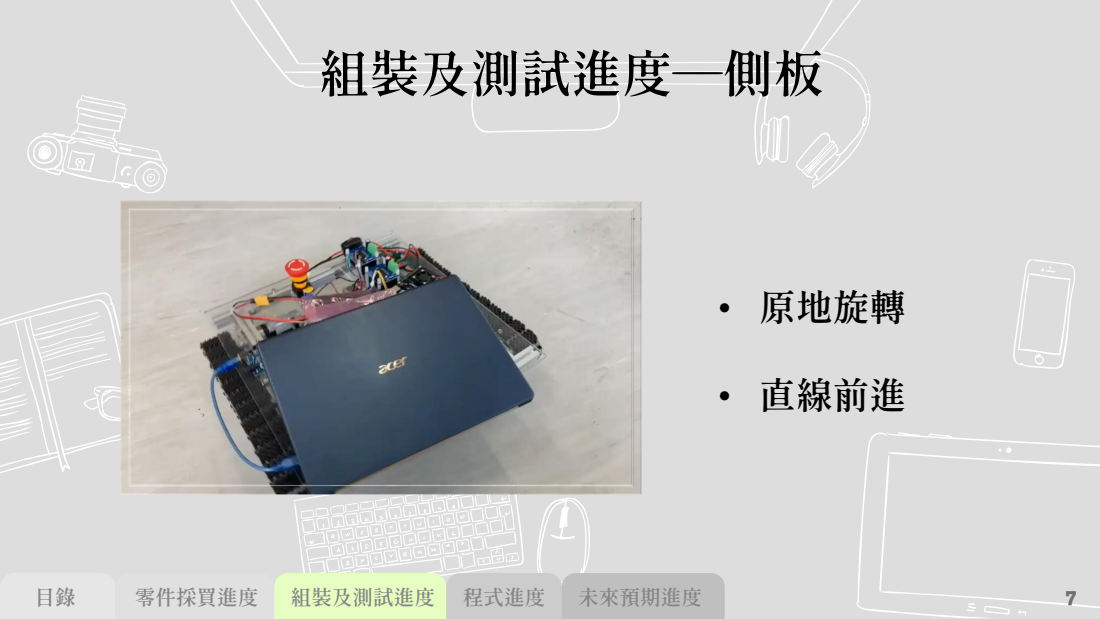
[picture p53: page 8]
• 原地旋轉; • 直線前進

# 程式進度

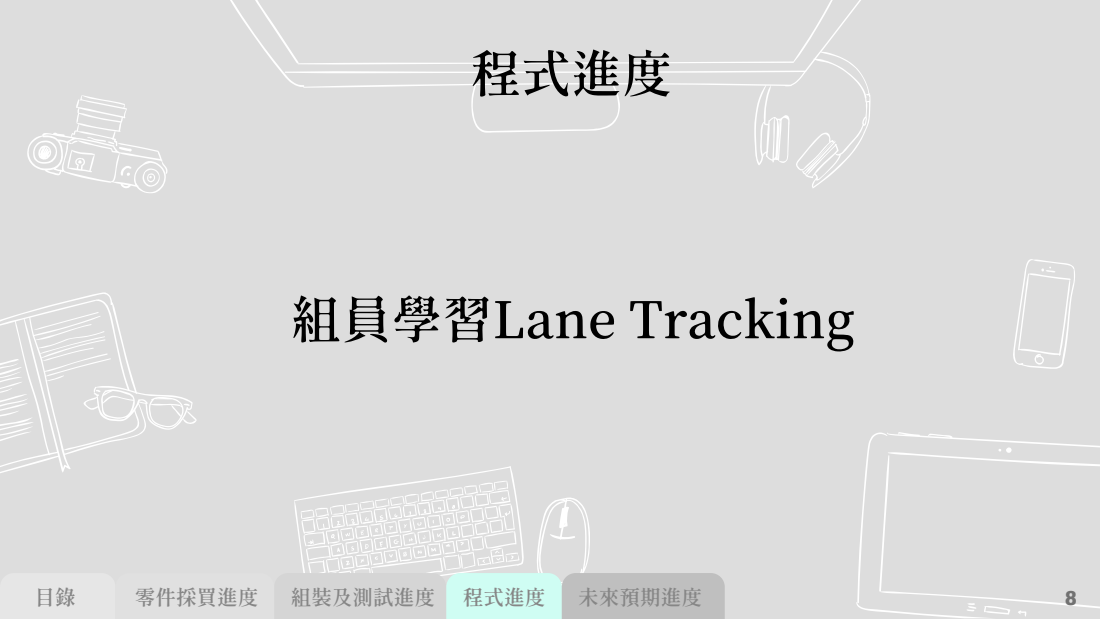
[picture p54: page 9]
組員學習Lane Tracking

# 未來預期進度

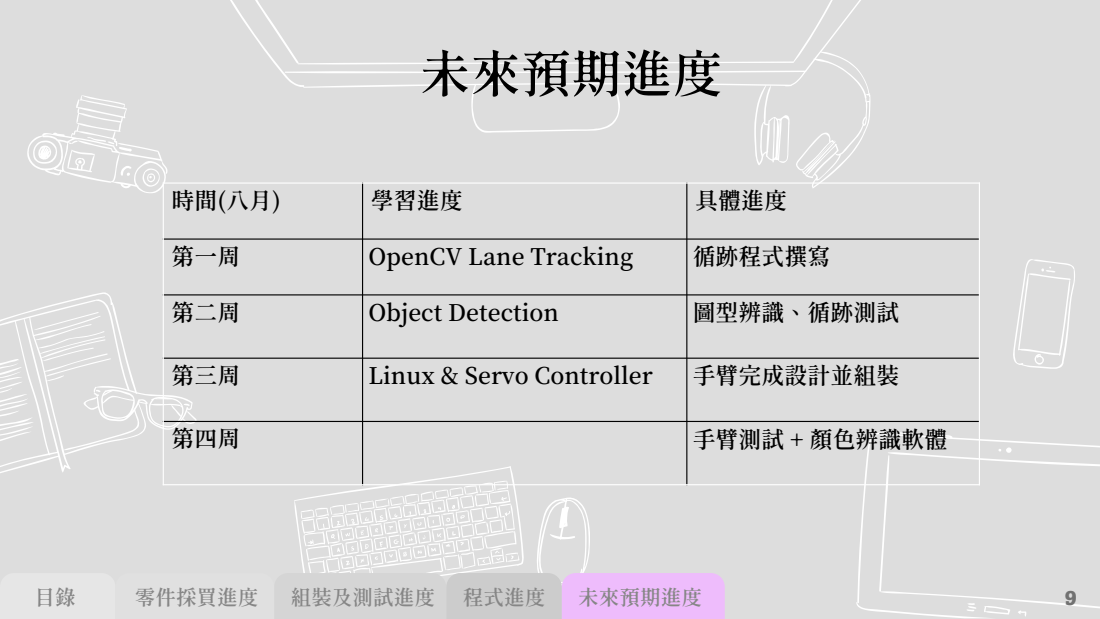
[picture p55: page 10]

時間(八月) | 學習進度 | 具體進度

第一周 | OpenCV Lane Tracking | 循跡程式撰寫

第二周 | Object Detection | 圖型辨識、循跡測試

第三周 | Linux & Servo Controller | 手臂完成設計並組裝

第四周 | | 手臂測試 + 顏色辨識軟體

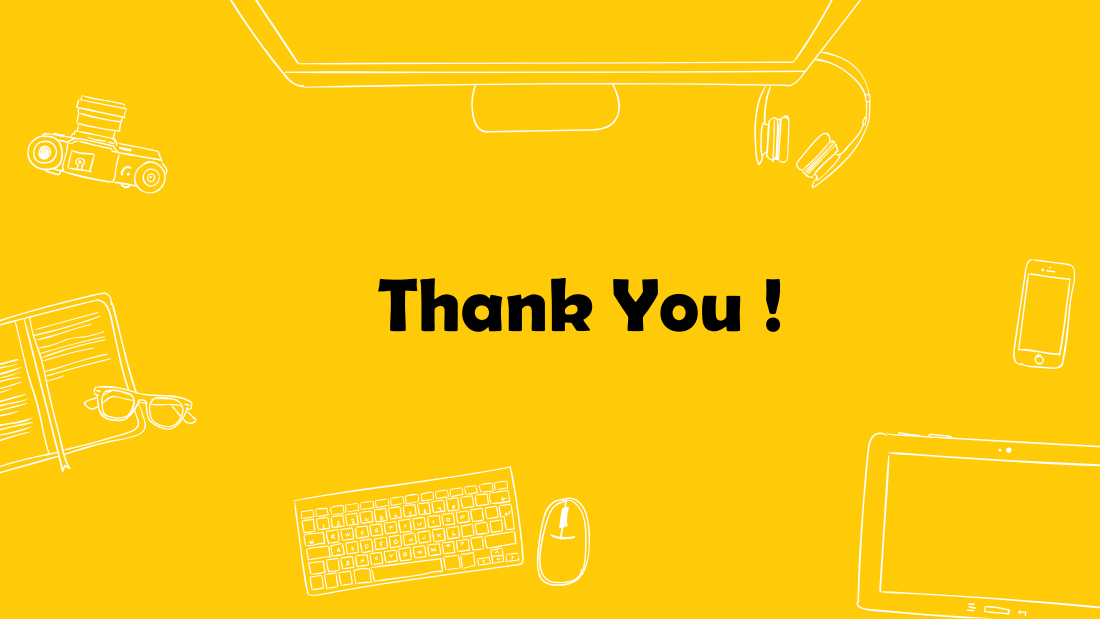
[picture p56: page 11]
Thank You !

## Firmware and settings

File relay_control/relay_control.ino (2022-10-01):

char flag = '1'; // flag for the execuate signal

void setup() {
 pinMode(8,OUTPUT); // the relay info pin
 Serial.begin(9600);
}

void loop() {
  if(Serial.available()){
    flag = Serial.read();
    Serial.println(Num);
  } 
  
  delay(10);
  
  if(flag == '1'){
    digitalWrite(8,LOW);
  }
  else{
    digitalWrite(8,HIGH);
  }
}

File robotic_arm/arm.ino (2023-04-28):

#include "arm.h"
arm a(0x40, 60);
char flag = '0';

void setup() {
  Serial.begin(9600);
  a.initialize();

}

void loop() {
  if(Serial.available()){
    flag = Serial.read();
  }
  switch(flag){
    case '0':
      a.resetInit();
      break;
    case '1':
      a.moveTo(20, 0);
      break;
    case '3':
      a.grab();
      break;
    case '4':
      a.moveTo(30, 30);
      break;
    case '5':
      a.ungrab();
      break;
  }
}

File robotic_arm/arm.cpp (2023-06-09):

// The source code for dummy robotic arm control
// author: Po-Ting Ko
// last updated on 11/04/2022
// Compatible with the Arduino IDE 1.0
// Library version:1.1

#include "arm.h"

arm::arm(int i2c_address, int frequency){
  address = i2c_address; freq = frequency;  
}

void arm::initialize(){
  // Initialize the pwm server driver
  Adafruit_PWMServoDriver driver = Adafruit_PWMServoDriver(address);
  driver.begin(); driver.setPWMFreq(freq);

  maxPWM1 = int(float(2500)/1000000 *freq * 4096);
  maxPWM2 = int(float(2400)/1000000 *freq * 4096);
  minPWM = int(float(500)/1000000 *freq * 4096);
  maxAngle1 = 300; maxAngle2 = 180;
}

void arm::resetInit(){
  driver.setPWM(0, 0, angleToPulse1(50));
  driver.setPWM(1, 0, angleToPulse1(100));
  driver.setPWM(2, 0, angleToPulse2(0));
}

void arm::moveTo(int x, int y){
  double a1 = 21.375; 
  double a2 = 24.000;
  double l = sqrt(pow(x, 2)+ pow(y, 2)); // ratation axis to end direation distance

  double a = y / l;
  double b = (pow(l, 2) + pow(a1, 2) - pow(a2, 2))/(2 * l * a1);
  double c = (pow(a1, 2) + pow(a2, 2) - pow(l, 2))/(2 * a1 * a2);

  double theta2 = atan2(a, sqrt(1 - pow(a, 2))) + atan2(sqrt(1 - pow(b, 2)), b);
  double theta3 = atan2(sqrt(1 - pow(c, 2)), c);
  theta2 = int(theta2 * 180 / PI);
  theta3 = int(theta3 * 180 / PI);
  int theta1 = 180 - theta2 - theta3;

  driver.setPWM(0, 0, angleToPulse1(theta1));
  driver.setPWM(1, 0, angleToPulse1(theta2));
}

void arm::grab(){
  driver.setPWM(2, 0, angleToPulse2(180));
}

void arm::ungrab(){
  driver.setPWM(2, 0, angleToPulse2(0));
}

int arm::angleToPulse1(int angle){
  return map(angle, 0, maxAngle1, minPWM, maxPWM1);
}

int arm::angleToPulse2(int angle){
  return map(angle, 0, maxAngle2, minPWM, maxPWM2);
}

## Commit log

2022-08-18 Add the driver, lane detection and misc file
2022-08-22 Add camera calibration code
2022-09-16 update servo test
2022-09-27 add the SLDPRT file of robotic arm design
    [483.SLDPRT, arm1.SLDPRT, arm2.SLDPRT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]
2022-10-01 add relay control file
2022-10-14 servo motor test code w/ calib
2022-10-14 update servo test code
2022-10-18 arm controll done
2022-10-19 arm code file
2023-04-28 update the source codes and hardware designs
    [483_bear.SLDPRT, arm1.SLDPRT, arm2.SLDPRT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]
2023-04-28 update and modify
    [483.SLDPRT, arm1.SLDPRT, arm2.SLDPRT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]
